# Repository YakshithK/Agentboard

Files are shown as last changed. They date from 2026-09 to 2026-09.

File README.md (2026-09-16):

# AgentBoard

A macropad for controlling Claude Code and Codex sessions. The hardware design is currently complete; the build is a work in progress.

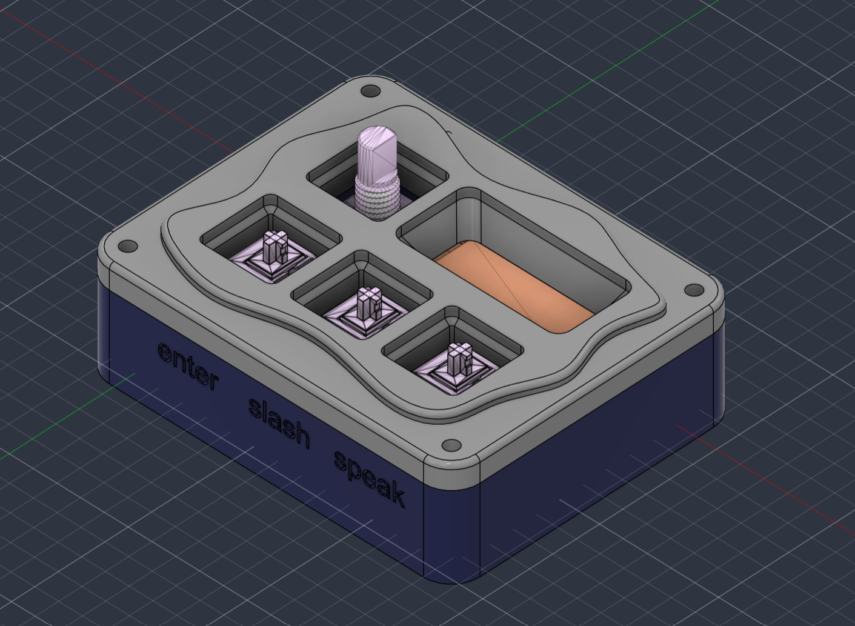
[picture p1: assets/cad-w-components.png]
AgentBoard CAD with PCB and hardware assembled


| Top | Bottom |
| --- | --- |
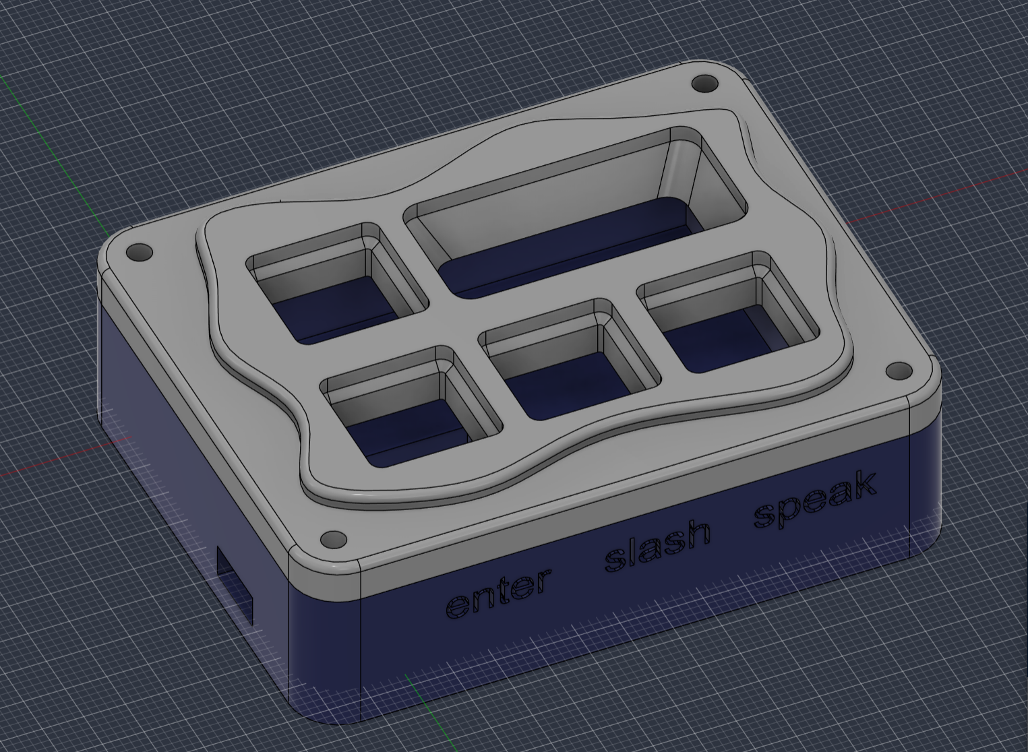
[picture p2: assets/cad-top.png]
CAD top view with components
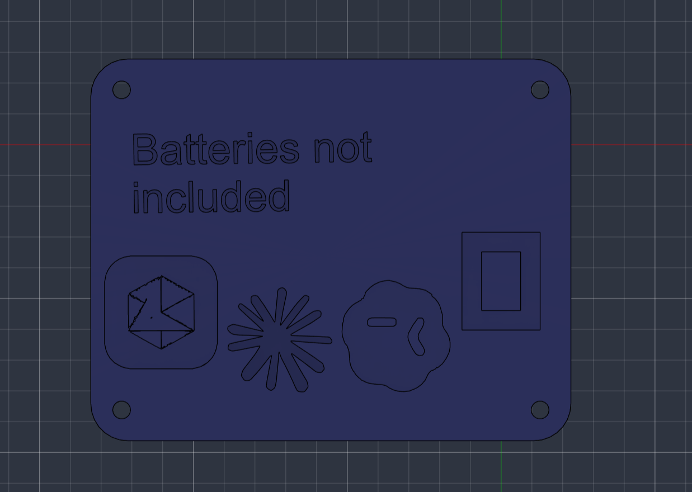
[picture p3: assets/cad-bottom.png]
CAD bottom view
|  |  |

## Features
- 3 Keys: forward slash for commands, enter (obviously), push-to-talk
- Encoder to shuffle between answer choices
- Encoder switch to shuffle between permission modes

## Technical Details

The board is built around the XIAO RP2040, three push buttons, an Alps EC11 rotary encoder with switch, and a 128x32 SSD1306 OLED connected over I2C.

| Schematic | PCB Layout |
| --- | --- |
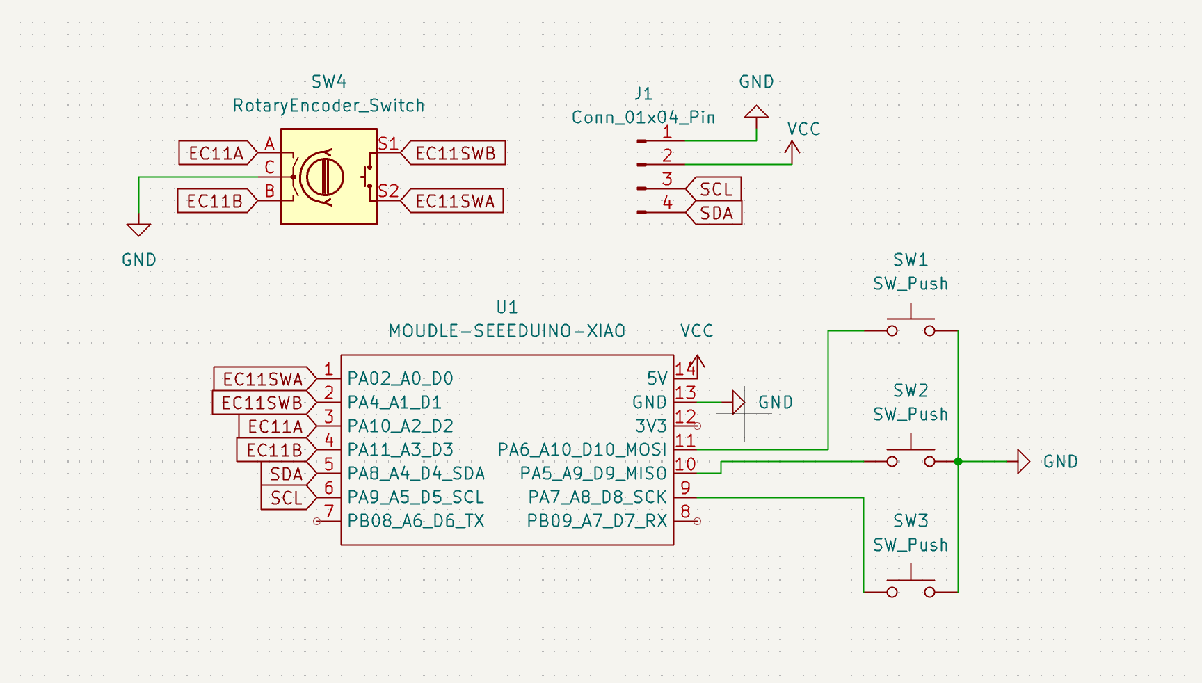
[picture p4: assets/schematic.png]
Schematic
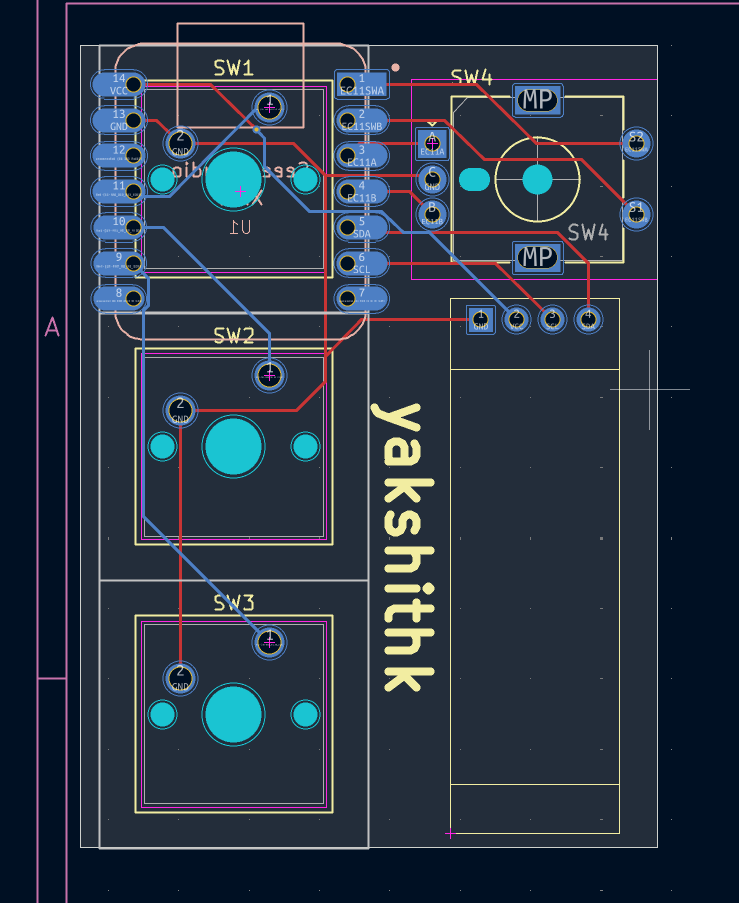
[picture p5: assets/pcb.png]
PCB layout
|  |  |

## Bill of Materials

Full machine-readable list: [`BOM.csv`](BOM.csv)

| Item | Reference | Qty | Part | Notes |
| --- | --- | --- | --- | --- |
| 1 | U1 | 1 | Seeed Studio XIAO RP2040 | RP2040-based USB microcontroller module |
| 2 | SW1-SW3 | 3 | MX-style mechanical switch | Any Cherry MX compatible switch |
| 3 | SW4 | 1 | Alps EC11E rotary encoder | With integrated push switch, vertical, 20mm shaft |
| 4 | J1 | 1 | 0.91" SSD1306 OLED | 128x32, I2C, 4-pin header |
| 5 | PCB1 | 1 | AgentBoard PCB | 2-layer, order from JLCPCB/PCBWay |
| 6 | KN1 | 1 | Rotary encoder knob | 6mm D-shaft, optional |
| 7 | KC1-KC3 | 3 | 1u keycaps | Cherry MX profile |

## Motivation

I always wanted an easy way to control my sessions and having a small macropad definitely doesn't make a substantial decrease in ease of use however it tricks my mind into making it seem very effortless, compared to using an entire keyboard. Just 3-4 keys!

## Future

I really wish to add bluetooth support and maybe even wifi. Possibly turning this into a pocket agent that you can take with you and allows you to control your sessions remotely. However this isn't much different from the Claude/GPT app so I need to narrow the scope down a little more. Another direction I was looking into was a desktop buddy. Need to explore more. 

## Repo Index

### Start Here

| Path | Purpose |
| --- | --- |
| [`README.md`](README.md) | Project overview, features, motivation, and this repository map |
| [`BOM.csv`](BOM.csv) | Bill of materials |
| [`firmware/readme.md`](firmware/readme.md) | QMK build and flashing notes |

### Hardware: KiCad

| Path | Purpose |
| --- | --- |
| [`agentboard_pcb/AgentBoard.kicad_pro`](agentboard_pcb/AgentBoard.kicad_pro) | KiCad project settings |
| [`agentboard_pcb/AgentBoard.kicad_sch`](agentboard_pcb/AgentBoard.kicad_sch) | Source schematic |
| [`agentboard_pcb/AgentBoard.kicad_pcb`](agentboard_pcb/AgentBoard.kicad_pcb) | Source PCB layout |

### Hardware: CAD Files

| Path | Purpose |
| --- | --- |
| [`CAD/AgentBoard.step`](CAD/AgentBoard.step) | 3D CAD model in STEP format |
| [`PCB/AgentBoard.step`](PCB/AgentBoard.step) | 3D CAD model in STEP format |
| [`PCB/AgentBoard.stl`](PCB/AgentBoard.stl) | 3D CAD model in STL format |

### Hardware: Production Files

| Path | Purpose |
| --- | --- |
| [`production/AgentBoard.step`](production/AgentBoard.step) | STEP model bundled for fabrication |
| [`production/AgentBoard-gerbers.zip`](production/AgentBoard-gerbers.zip) | Zipped Gerbers + drill, ready to upload to the fab |
| [`production/gerbers/`](production/gerbers/) | Gerber plot, drill, and pick-and-place files |
| [`production/firmware/`](production/firmware/) | QMK firmware source for flashing |

### Hardware: Visual References

| Path | Purpose |
| --- | --- |
| [`assets/schematic.png`](assets/schematic.png) | Schematic preview |
| [`assets/pcb.png`](assets/pcb.png) | PCB layout preview |
| [`assets/cad-top.png`](assets/cad-top.png) | Top-side CAD preview |
| [`assets/cad-bottom.png`](assets/cad-bottom.png) | Bottom-side CAD preview |
| [`assets/cad-w-components.png`](assets/cad-w-components.png) | CAD preview with components |

### Firmware: QMK

| Path | Purpose |
| --- | --- |
| [`firmware/keyboard.json`](firmware/keyboard.json) | Keyboard identity, RP2040 target, pins, layout, and enabled features |
| [`firmware/rules.mk`](firmware/rules.mk) | QMK board, OLED, I2C, and encoder build settings |
| [`firmware/config.h`](firmware/config.h) | I2C pins, OLED address/size, encoder resolution, and timeouts |
| [`firmware/agentboard.h`](firmware/agentboard.h) | Keyboard header included by QMK |
| [`firmware/keymaps/default/keymap.c`](firmware/keymaps/default/keymap.c) | Default keymap, custom keycodes, encoder actions, and OLED status screen |

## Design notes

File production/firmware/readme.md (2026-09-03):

# agentboard

agentboard

*A short description of the keyboard/project*

* Keyboard Maintainer: [Yakshith K](https://github.com/Yakshith K)
* Hardware Supported: *The PCBs, controllers supported*
* Hardware Availability: *Links to where you can find this hardware*

Make example for this keyboard (after setting up your build environment):

    make agentboard:default

Flashing example for this keyboard:

    make agentboard:default:flash

See the [build environment setup](https://docs.qmk.fm/#/getting_started_build_tools) and the [make instructions](https://docs.qmk.fm/#/getting_started_make_guide) for more information. Brand new to QMK? Start with our [Complete Newbs Guide](https://docs.qmk.fm/#/newbs).

## Bootloader

Enter the bootloader in 3 ways:

* **Bootmagic reset**: Hold down the key at (0,0) in the matrix (usually the top left key or Escape) and plug in the keyboard
* **Physical reset button**: Briefly press the button on the back of the PCB - some may have pads you must short instead
* **Keycode in layout**: Press the key mapped to `QK_BOOT` if it is available

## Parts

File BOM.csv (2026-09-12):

Item | Reference | Quantity | Part | Description | Footprint | Notes
1 | U1 | 1 | Seeed Studio XIAO RP2040 | Raspberry Pi RP2040 based USB microcontroller module | XIAO-Generic-Hybrid-14P-2.54-21X17.8MM
2 | SW1, SW2, SW3 | 3 | MX-style mechanical switch | Push button switch (cherry MX compatible) | SW_Cherry_MX_1.00u_PCB | Any MX compatible switch works
3 | SW4 | 1 | Alps EC11E rotary encoder | Rotary encoder with integrated push switch (vertical, 20mm shaft) | RotaryEncoder_Alps_EC11E-Switch_Vertical_H20mm_MountingHoles
4 | J1 | 1 | 0.91 in SSD1306 OLED display | 128x32 monochrome OLED module with I2C interface | SSD1306-0.91-OLED-4pin-128x32 | 4-pin header (GND VCC SCL SDA)
5 | PCB1 | 1 | AgentBoard PCB | 2-layer KiCad PCB |  | Order from JLCPCB, PCBWay, or similar
6 | KN1 | 1 | Rotary encoder knob | Knob compatible with 6mm D-shaft EC11 encoder |  | Optional depending on enclosure
7 | KC1-KC3 | 3 | 1u keycaps | Cherry MX profile keycaps

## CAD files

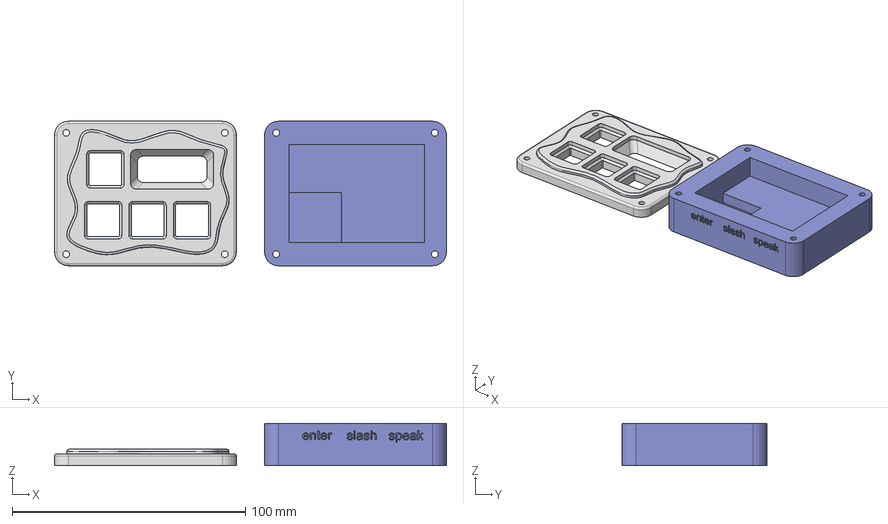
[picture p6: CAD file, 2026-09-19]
CAD/AgentBoard.step
168.0 x 62.0 x 18.0 mm

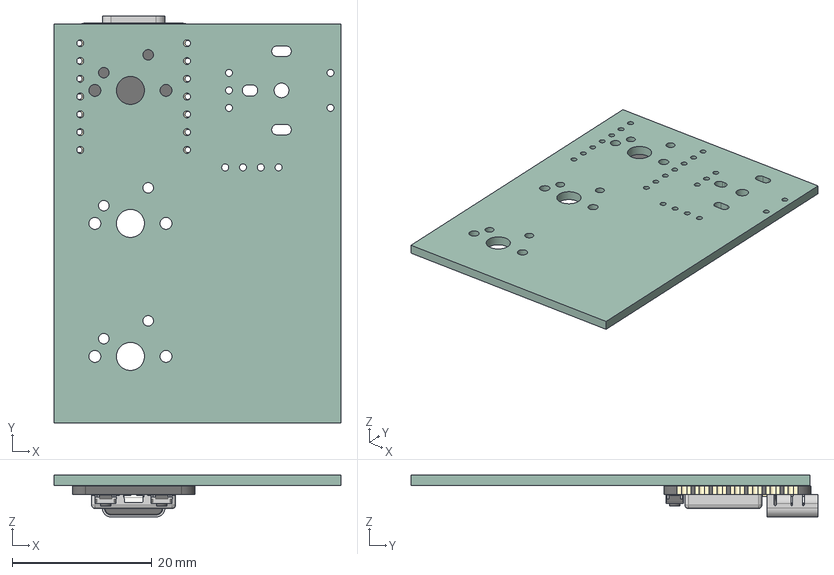
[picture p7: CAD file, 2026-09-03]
production/AgentBoard.step
41.0 x 58.1 x 6.00 mm
type-c v2
smd_button v3
DOUT
DIN
VSS
VDD
smd_button v3(Mirror)
Bal3C8F_PCB

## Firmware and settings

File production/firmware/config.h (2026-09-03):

#pragma once

// ==============================
// I2C
// ==============================

#define I2C_DRIVER I2CD1
#define I2C1_SDA_PIN GP6
#define I2C1_SCL_PIN GP7

// ==============================
// OLED
// ==============================

#define OLED_IC OLED_IC_SSD1306
#define OLED_DISPLAY_ADDRESS 0x3C
#define OLED_DISPLAY_128X32

// ==============================
// Encoder
// ==============================

#define ENCODER_RESOLUTION 4

// ==============================
// RP2040 bootloader
// ==============================

#define RP2040_BOOTLOADER_DOUBLE_TAP_RESET
#define RP2040_BOOTLOADER_DOUBLE_TAP_RESET_TIMEOUT 200U

// ==============================
// OLED power / refresh
// ==============================

#define OLED_TIMEOUT 30000
#define OLED_UPDATE_INTERVAL 100

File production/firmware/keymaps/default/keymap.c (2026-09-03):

// Copyright 2023 QMK
// SPDX-License-Identifier: GPL-2.0-or-later

#include QMK_KEYBOARD_H

enum custom_keycodes {
    CTRL_GUI = SAFE_RANGE,
    ENC_SHIFT_TAB
};

const uint16_t PROGMEM keymaps[][MATRIX_ROWS][MATRIX_COLS] = {
    [0] = LAYOUT(
        KC_ENT,        // SW1
        KC_SLSH,       // SW2
        CTRL_GUI,      // SW3
        ENC_SHIFT_TAB  // Encoder switch
    )
};

bool process_record_user(uint16_t keycode, keyrecord_t *record) {
    switch (keycode) {
        case CTRL_GUI:
            if (record->event.pressed) {
                register_code(KC_LCTL);
                register_code(KC_LGUI);
            } else {
                unregister_code(KC_LGUI);
                unregister_code(KC_LCTL);
            }
            return false;

        case ENC_SHIFT_TAB:
            if (record->event.pressed) {
                tap_code16(S(KC_TAB));
            }
            return false;
    }

    return true;
}

#if defined(ENCODER_MAP_ENABLE)

const uint16_t PROGMEM encoder_map[][NUM_ENCODERS][NUM_DIRECTIONS] = {
    [0] = {
        ENCODER_CCW_CW(KC_UP, KC_DOWN)
    }
};

#endif

#ifdef OLED_ENABLE

bool oled_task_user(void) {
    oled_clear();

    oled_write_ln_P(PSTR("AGENTBOARD"), false);
    oled_write_ln_P(PSTR("----------"), false);

    oled_write_P(PSTR("SW1: ENTER\n"), false);
    oled_write_P(PSTR("SW2: /\n"), false);
    oled_write_P(PSTR("SW3: CTRL+WIN\n"), false);
    oled_write_P(PSTR("ENC: SHIFT+TAB"), false);

    return false;
}

#endif

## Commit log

2026-09-03 readme and assets
    [AgentBoard.kicad_pcb]
2026-09-12 add BOM.csv, move CAD exports to PCB/, embed renders in README
    [AgentBoard.step, BOM.csv]
2026-09-14 add CAD and production folders with gerbers, step, firmware; show schematic and pcb in README
    [AgentBoard-B_Adhesive.gbr, AgentBoard-B_Courtyard.gbr, AgentBoard-B_Cu.gbr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]
2026-09-16 zip gerbers, add built uf2 firmware to production
2026-09-19 chore: update CAD case STEP from Fusion export
    Replace the KiCad PCB copy with the Fusion enclosure export
    (case 78x62x18mm + plate, both verified watertight per-body).
    Part of #1
    [AgentBoard.step]
